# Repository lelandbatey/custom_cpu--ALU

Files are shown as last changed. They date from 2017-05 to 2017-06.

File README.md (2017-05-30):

Arithmetic Logic Unit (ALU)
===========================

This repo contains PCB designs for the third component of Ben Eater's
educational 8-bit CPU, the arithmetic logic unit or ALU. You can [watch Mr.
Eaters *fantastic* series on designing and building this CPU on his Youtube
channel.](https://www.youtube.com/user/eaterbc/videos)

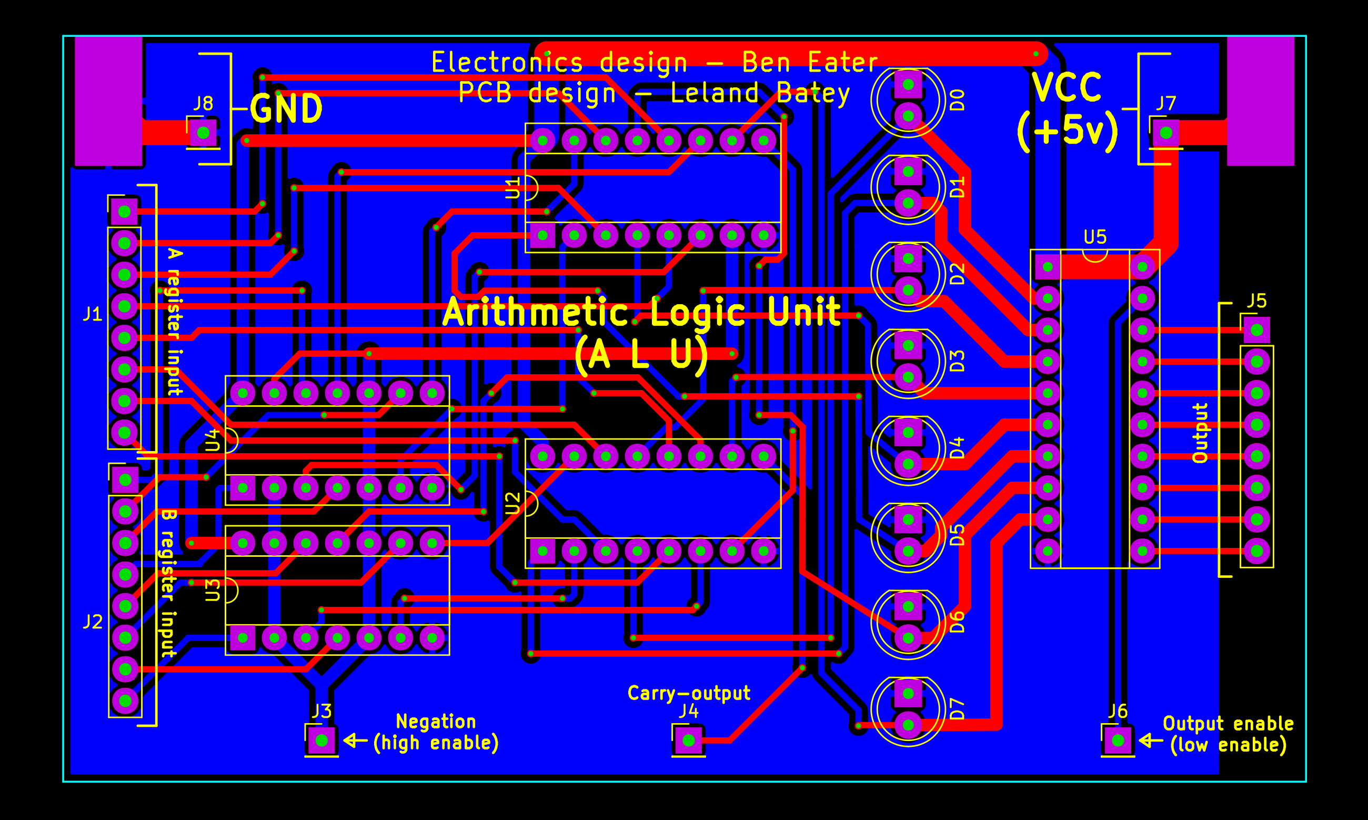
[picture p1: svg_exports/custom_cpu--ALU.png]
Render of the ALU PCB


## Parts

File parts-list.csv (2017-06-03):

ALU Parts List
Part Name | Count | Unit Price | Total Price | Total Price of ALL Materials
LED (yellow) | 8 | $0.20 | $1.60 | $9.87
Pin header, 1x8 | 3 | $0.86 | $2.58
20 Pin DIP socket | 1 | $0.24 | $0.24
16 Pin DIP socket | 2 | $0.18 | $0.36
14 Pin DIP socket | 2 | $0.21 | $0.42
74LS283 (4-bit adder) | 2 | $1.38 | $2.76
74LS86 (XOR) | 2 | $0.52 | $1.04
74LS245 (bus transceiver) | 1 | $0.87 | $0.87

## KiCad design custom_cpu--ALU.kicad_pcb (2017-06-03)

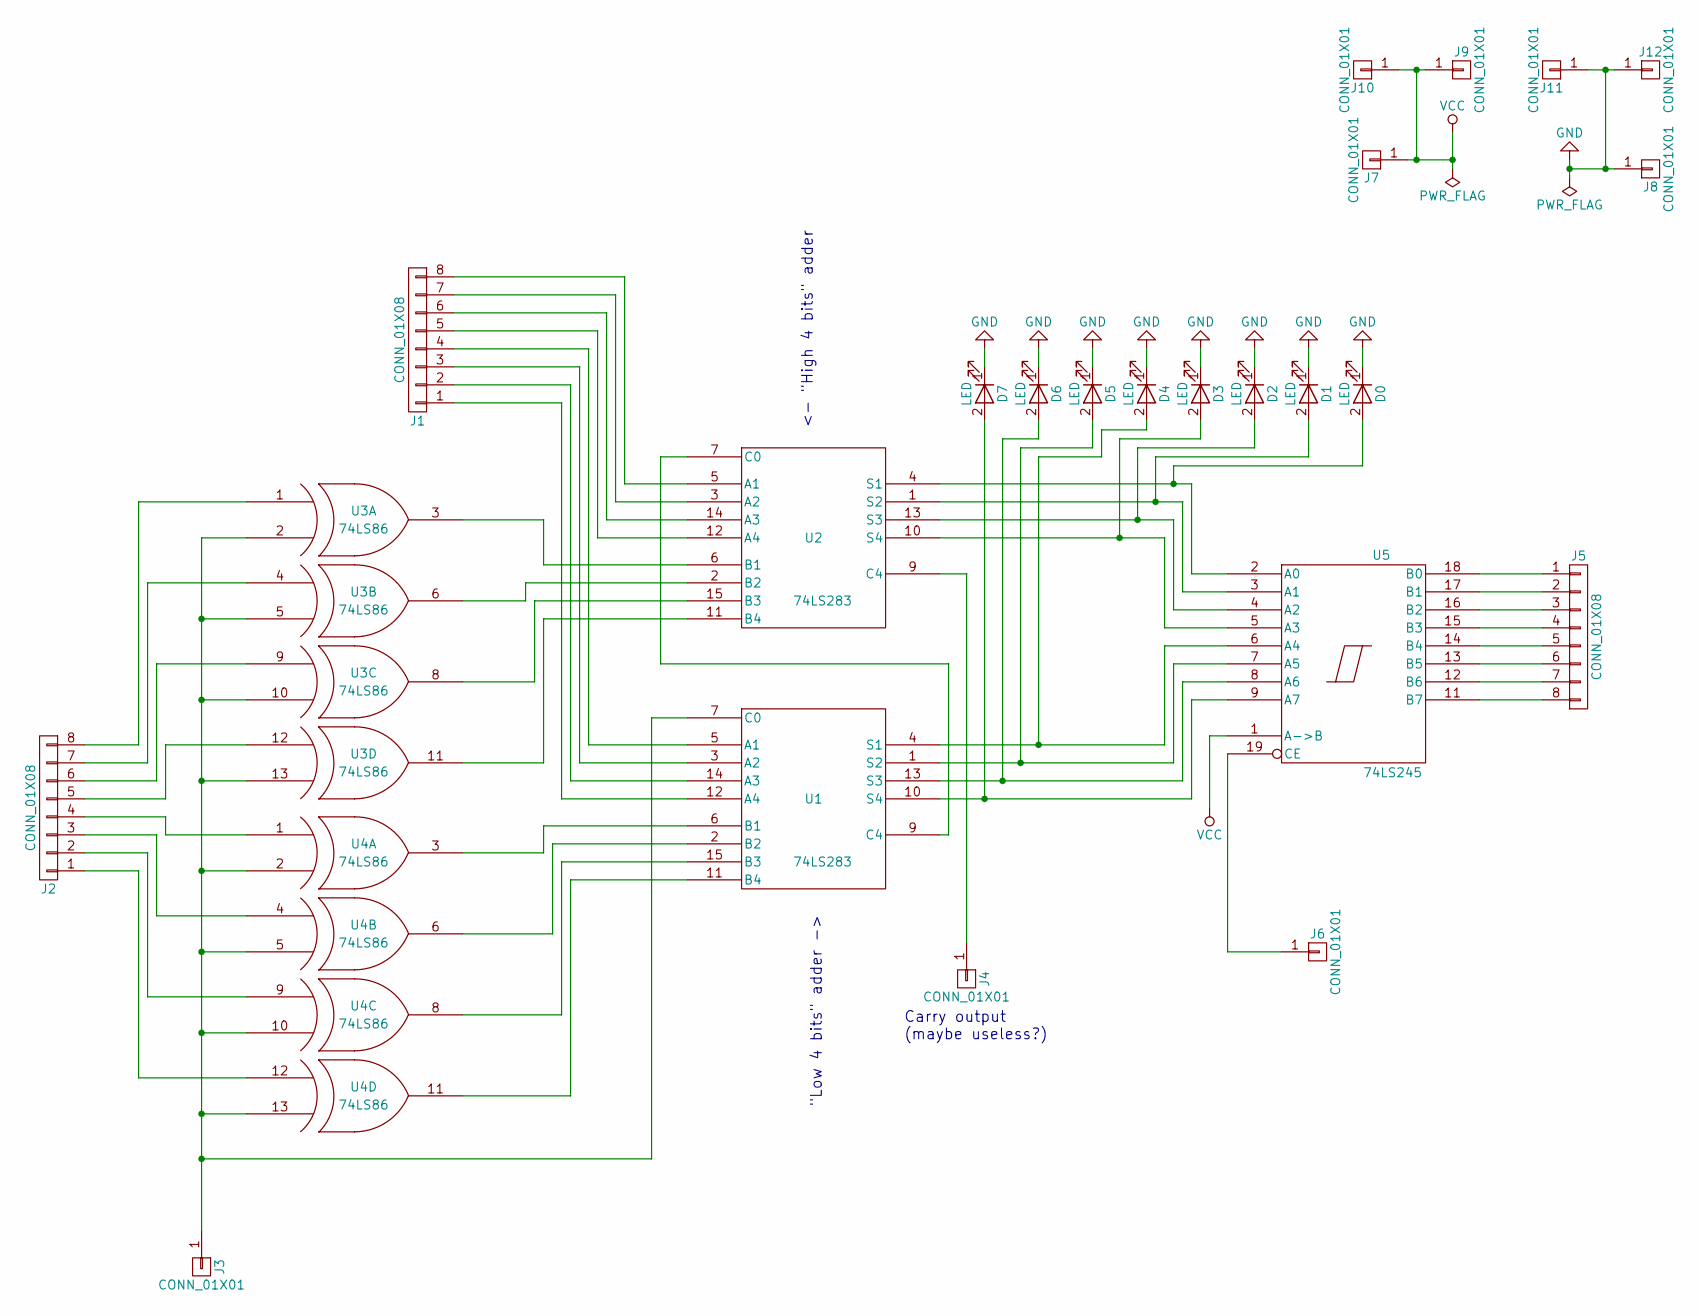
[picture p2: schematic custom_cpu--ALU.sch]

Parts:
D0, D1, D2, D3, D4, D5, D6, D7: LED; LED_D5.0mm
J1, J2, J5: CONN_01X08; Pin_Header_Straight_1x08_Pitch2.54mm
J3, J4, J6, J7, J8: CONN_01X01; Pin_Header_Straight_1x01_Pitch2.54mm
J9, J10, J11, J12: CONN_01X01; SolderWirePad_single_SMD_5x10mm
U1, U2: 74LS283; DIP-16_W7.62mm_Socket
U3, U4: 74LS86; DIP-14_W7.62mm_Socket
U5: 74LS245; DIP-20_W7.62mm_Socket

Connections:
GND: D0.1 (K), D1.1 (K), D2.1 (K), D3.1 (K), D4.1 (K), D5.1 (K), D6.1 (K), D7.1 (K), J8.1, J11.1, J12.1, U1.8 (GND), U2.8 (GND), U3.7 (GND), U4.7 (GND), U5.10 (GND)
unnamed: D0.2 (A), U2.4 (S1), U5.2 (A0)
unnamed: D1.2 (A), U2.1 (S2), U5.3 (A1)
unnamed: D2.2 (A), U2.13 (S3), U5.4 (A2)
unnamed: D3.2 (A), U2.10 (S4), U5.5 (A3)
unnamed: D4.2 (A), U1.4 (S1), U5.6 (A4)
unnamed: D5.2 (A), U1.1 (S2), U5.7 (A5)
unnamed: D6.2 (A), U1.13 (S3), U5.8 (A6)
unnamed: D7.2 (A), U1.10 (S4), U5.9 (A7)
unnamed: J1.1, U1.12 (A4)
unnamed: J1.2, U1.14 (A3)
unnamed: J1.3, U1.3 (A2)
unnamed: J1.4, U1.5 (A1)
unnamed: J1.5, U2.12 (A4)
unnamed: J1.6, U2.14 (A3)
unnamed: J1.7, U2.3 (A2)
unnamed: J1.8, U2.5 (A1)
unnamed: J2.1, U4.12 (IN1)
unnamed: J2.2, U4.9 (IN1)
unnamed: J2.3, U4.4 (IN1)
unnamed: J2.4, U4.1 (IN1)
unnamed: J2.5, U3.12 (IN1)
unnamed: J2.6, U3.9 (IN1)
unnamed: J2.7, U3.4 (IN1)
unnamed: J2.8, U3.1 (IN1)
unnamed: J3.1, U1.7 (C0), U3.2 (IN2), U3.5 (IN2), U3.10 (IN2), U3.13 (IN2), U4.2 (IN2), U4.5 (IN2), U4.10 (IN2), U4.13 (IN2)
unnamed: J4.1, U2.9 (C4)
unnamed: J5.1, U5.18 (B0)
unnamed: J5.2, U5.17 (B1)
unnamed: J5.3, U5.16 (B2)
unnamed: J5.4, U5.15 (B3)
unnamed: J5.5, U5.14 (B4)
unnamed: J5.6, U5.13 (B5)
unnamed: J5.7, U5.12 (B6)
unnamed: J5.8, U5.11 (B7)
unnamed: J6.1, U5.19 (CE)
unnamed: U1.2 (B2), U4.6 (OUT)
unnamed: U1.6 (B1), U4.3 (OUT)
unnamed: U1.9 (C4), U2.7 (C0)
unnamed: U1.11 (B4), U4.11 (OUT)
unnamed: U1.15 (B3), U4.8 (OUT)
unnamed: U2.2 (B2), U3.6 (OUT)
unnamed: U2.6 (B1), U3.3 (OUT)
unnamed: U2.11 (B4), U3.11 (OUT)
unnamed: U2.15 (B3), U3.8 (OUT)
VCC: J7.1, J9.1, J10.1, U1.16 (VCC), U2.16 (VCC), U3.14 (VCC), U4.14 (VCC), U5.1 (A->B), U5.20 (VCC)

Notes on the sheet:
"Low 4 bits" adder ->
<- "High 4 bits" adder
Carry output (maybe useless?)

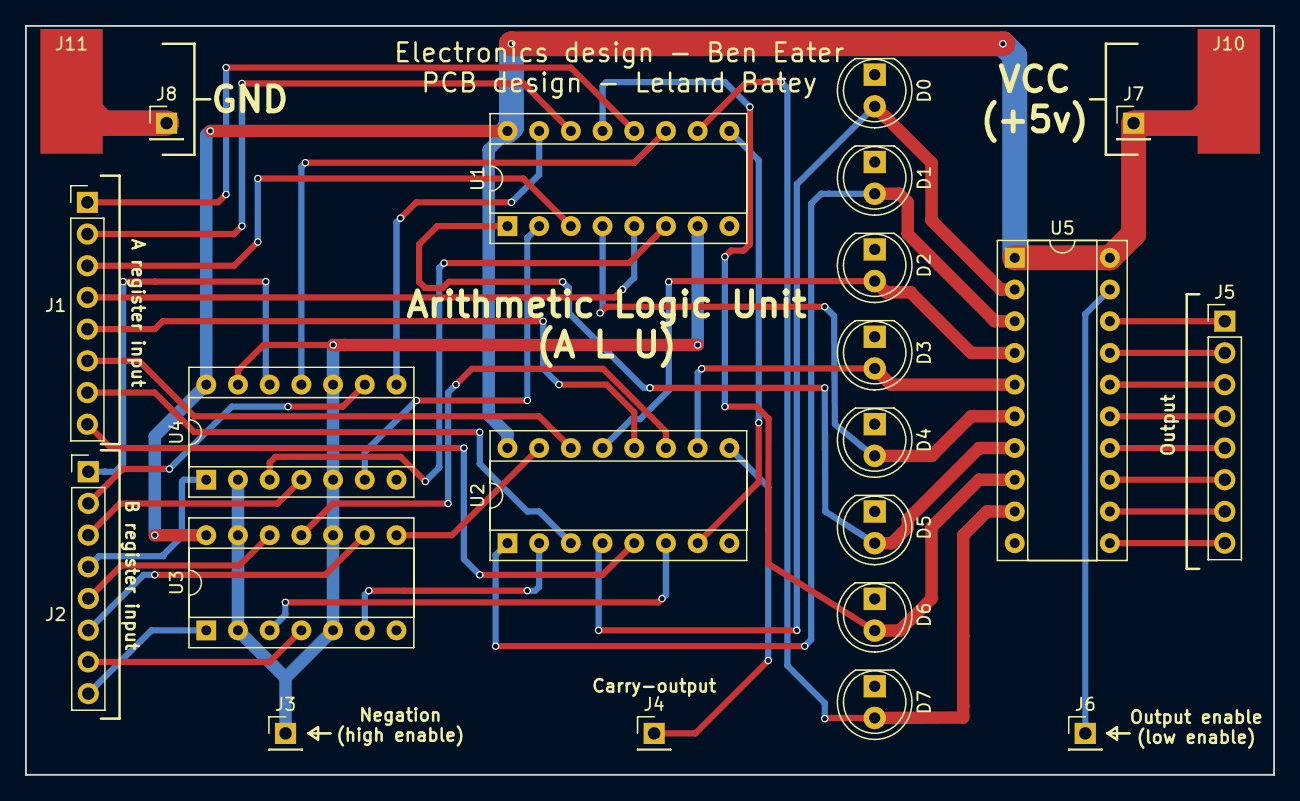
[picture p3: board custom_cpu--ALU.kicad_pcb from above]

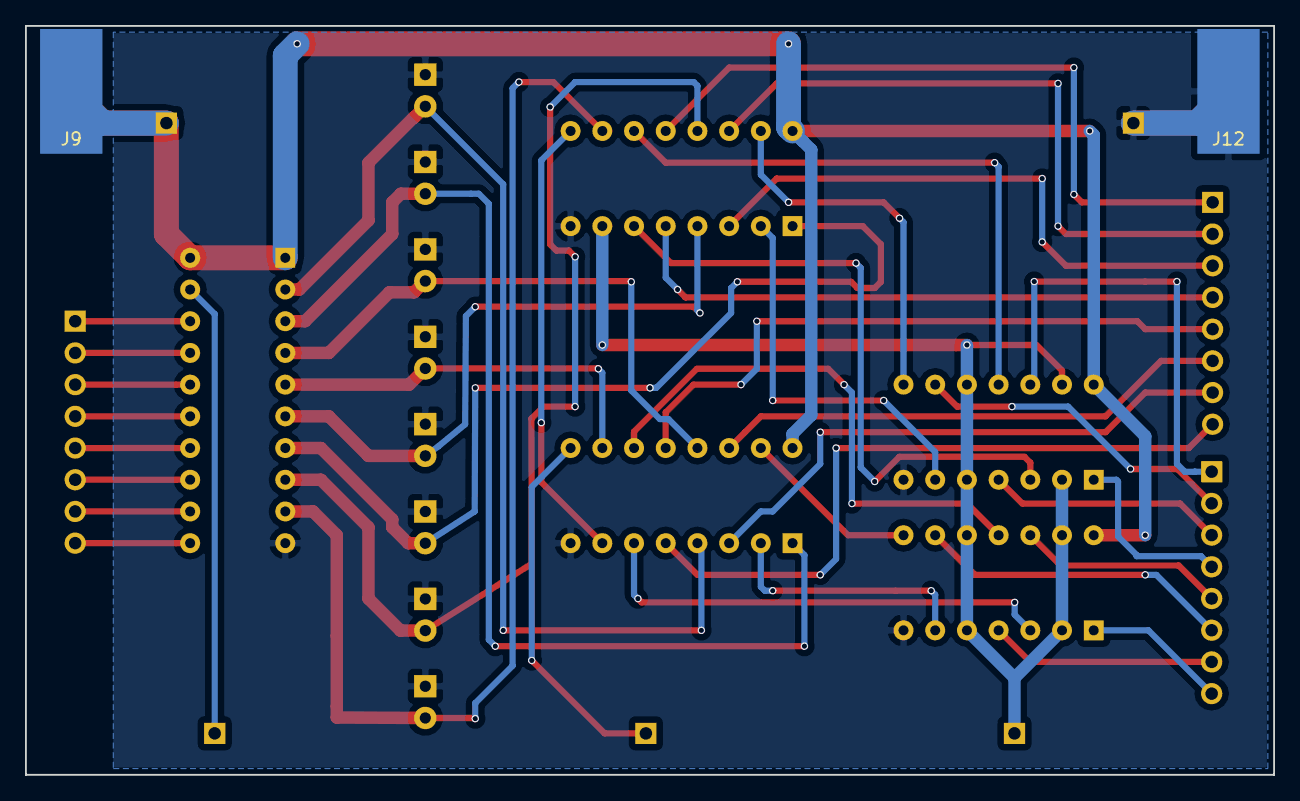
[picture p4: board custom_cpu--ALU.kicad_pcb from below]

Board: 2 copper layers, 100.0 x 60.0 mm, 25 parts (2 on the bottom side), 46 nets.

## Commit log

2017-06-01 Fix touching trace
    [custom_cpu--ALU.kicad_pcb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]
2017-06-01 fix a couple more touching traces
    [custom_cpu--ALU.kicad_pcb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]
2017-06-03 Add power labels
    [custom_cpu--ALU.kicad_pcb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]
2017-06-03 Fix input register labels
    [custom_cpu--ALU.kicad_pcb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]
2017-06-03 Add parts list and cost of materials
    [parts-list.csv]
